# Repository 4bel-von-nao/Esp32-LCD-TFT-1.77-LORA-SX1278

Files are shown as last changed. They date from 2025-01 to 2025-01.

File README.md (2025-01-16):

# Monitor de potencia con Esp32, LoRa y LCD TFT 1.77"
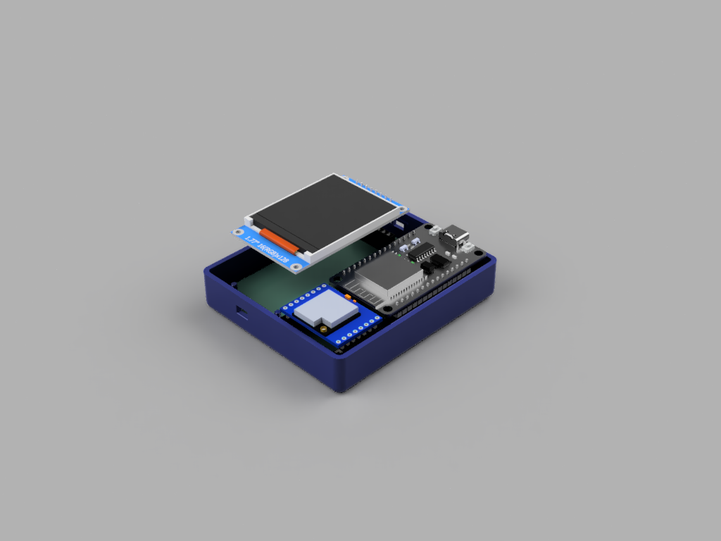
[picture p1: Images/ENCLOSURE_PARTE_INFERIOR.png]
imagen


Este proyecto consiste en un sistema de monitoreo de potencia eléctrica que utiliza un **ESP32** para recepcionar datos de corriente y voltaje
a través de un módulo **LoRa** para luego calcular la potencia consumida.
Se incluyen los diseños del circuito y la PCB realizados en **KiCAD**, y el modelo 3D del dispositivo en **Fusion 360**.

## Componentes principales

- ESP32 (Se usó la versión de 30 pines con conector tipo C).
- LoRa SX1278 RA02.
- LCD TFT 1.77".

## Archivos incluidos

- Codigo: Sketch Arduino
- Diseño PCB: Proyecto KiCad
- Modelos CAD: Archivo Fusion 360

## Problemas y Futuras mejoras

- Debido al intensivo uso del puerto SPI a causa del display LCD, se tuvo que usar puertos diferentes,
el puerto principal para el display y el puerto HSPI para el modulo LoRa, se modificó la libreria
LoRa de sandeepmistry para poder utilizar el puerto HSPI. En el futuro se buscará mejorar esto y poder 
usar un solo puerto para los dos perifericos.

- En el aspecto del diseño mecanico del enclosure, se intentó diseñar los anclajes por medio de tornillos
y roscas M3. Al momento de imprimir no salieron bien tales cuerpos y no pudo cumplir su función. Se replanteará
el diseño para algo más robusto, ya que los anlcajes a presión también son débiles.

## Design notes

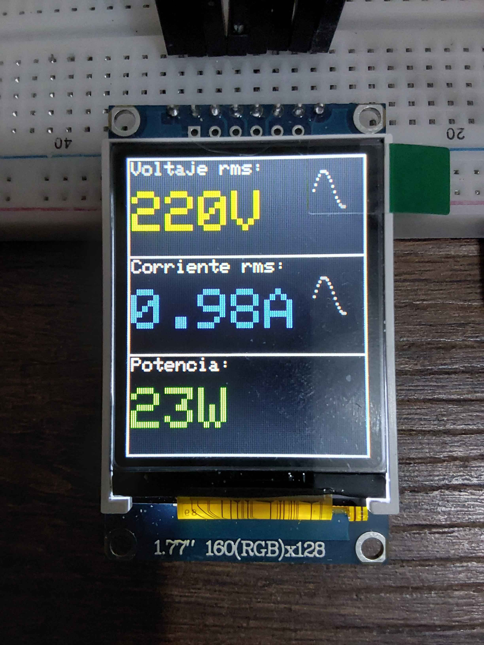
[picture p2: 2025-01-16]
Images/realfoto.jpg

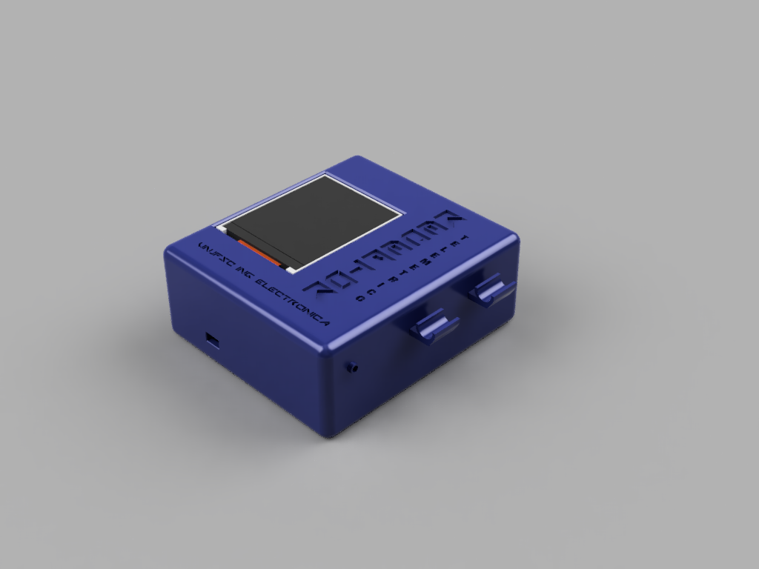
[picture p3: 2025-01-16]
Images/ENCLOSURE.png

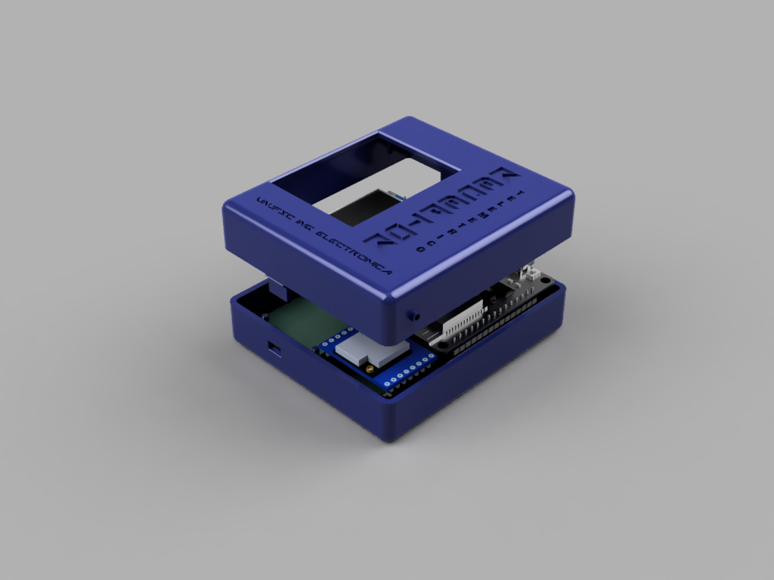
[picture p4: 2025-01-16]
Images/ENCLOSURE1.png

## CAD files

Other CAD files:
CadFiles/ENCLOSURE v9.f3z

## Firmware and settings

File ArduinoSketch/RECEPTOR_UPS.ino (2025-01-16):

#include <Adafruit_GFX.h>   
#include <Adafruit_ST7735.h> 
#include <SPI.h>
#include <LoRaHSPI.h>
//#include "esp_task_wdt.h"

#define TFT_CS 2
#define TFT_RST 21
#define TFT_DC 19
#define TFT_SCLK 18   
#define TFT_MOSI 23
#define BLANCO ST7735_WHITE
#define NEGRO ST7735_BLACK
#define AMARILLO ST7735_YELLOW
#define AZUL ST7735_BLUE
#define VERDE ST7735_GREEN

#define SS   15    // NSS (CS) conectado a GPIO15
#define RST  27     // RST conectado a GPIO27
#define DIO0 33    // DIO0 conectado a GPIO33

String idReceptor   = "TX1";  
String idTransmisor = "TX2";
String datos = "";
int voltaje;
unsigned long tiempoInicio = 0; 
unsigned long tiempoInicio2 = 0; 
int x = 100; int k = 100;
int i = 0;
float frecuencia = 0.3;
int amplitud = 10;
Adafruit_ST7735 tft = Adafruit_ST7735(TFT_CS, TFT_DC, TFT_MOSI, TFT_SCLK, TFT_RST);

void setup(void) {
  Serial.begin(9600);
  LoRa.setPins(SS, RST, DIO0);
  if (!LoRa.begin(433E6)) {  // Cambia la frecuencia según tu región
    Serial.println("Error al inicializar LoRa");
    while (1);
  }
  LoRa.setSpreadingFactor(7);         // SF igual al transmisor
  LoRa.setSignalBandwidth(250E3);    // Ancho de banda igual
  LoRa.setCodingRate4(5);            // Tasa de codificación igual
  LoRa.setPreambleLength(6);         // Preámbulo igual
  delay(1000);
  Serial.println("LoRa inicializado");
 
  xTaskCreate(Task1, "Tarea 1", 1000, NULL, 1, NULL);

  tft.initR(INITR_BLACKTAB);  
  tft.fillScreen(ST7735_BLACK);   
  tft.setTextColor(ST7735_WHITE);
  tft.setTextSize(0);
  tft.setCursor(30,80);
  tft.println("Hello World!");  
  delay(1000);
  tft.fillScreen(ST7735_BLACK); 
  tft.drawRect(0, 0, 128, 160, BLANCO);
  tft.drawLine(0, 53, 128, 53, BLANCO);
  tft.drawLine(0, 106, 128, 106, BLANCO);
}

void loop() { 
  if(millis()-tiempoInicio >= 100){
    rayo();
    seno1();
    seno2();
    tiempoInicio = millis();
  }
  if(millis()-tiempoInicio2 >= 1000){
    Voltaje();
    corriente(datos);
    potencia(datos,voltaje);
    tiempoInicio2 = millis();
  }
}

void Task1(void *pvParameters) {
  while(1) {
    vTaskDelay(10);                        // DELAY DE 10 TICS... O DESACTIVO EL PERRO O LE PONGO EL DELAY
     // Verificar si hay paquetes disponibles
    int packetSize = LoRa.parsePacket();
    if (packetSize) {
      String recibido = "";
      while (LoRa.available()) {
        recibido += (char)LoRa.read();
      }

      // Verificar si el mensaje tiene el identificador correcto
      if (recibido.startsWith(idTransmisor + ":")) {
        datos = recibido.substring(idTransmisor.length() + 1); // Extraer datos después de ":"
        Serial.println(datos);
        int pos1 = datos.indexOf(',');
        int pos2 = datos.indexOf(',');
        datos = datos.substring(0,pos1);
      } else {
        Serial.println("Paquete ignorado: " + recibido);
      }
    }
  }
}

void Voltaje(){
  tft.fillRect(2,16,87,25,NEGRO);
  voltaje = 220;
  voltaje = voltaje + random(-1,1);
  String voltaje2 = String(voltaje);
  tft.setTextColor(BLANCO);
  tft.setTextSize(1);
  tft.setCursor(2,2);
  tft.print("Voltaje rms:");
  tft.setTextColor(AMARILLO);
  tft.setCursor(2,18);
  tft.setTextSize(3);
  tft.print("220"); tft.print("V");
}

void corriente(String datos){
  tft.fillRect(2,71,87,21,NEGRO);
  tft.setTextColor(BLANCO);
  tft.setTextSize(1);
  tft.setCursor(2,55);
  tft.print("Corriente rms:");
  tft.setTextColor(AZUL);
  tft.setCursor(2,71);
  tft.setTextSize(3);
  tft.print(datos); tft.print("A"); 
}

void potencia(String datos, int voltaje){
  tft.fillRect(2,124,87,21,NEGRO);
  float potencia;
  float corriente = datos.toFloat();
  potencia = corriente * voltaje;
  tft.setTextColor(BLANCO);
  tft.setTextSize(1);
  tft.setCursor(2,108);
  tft.print("Potencia:");
  tft.setTextColor(VERDE);
  tft.setCursor(2,124);
  tft.setTextSize(3);
  tft.print(potencia); tft.print("W");
}

void seno1(){
    float seno = amplitud*sin(frecuencia*(x-100));
    int y = 18 - seno;
    tft.drawPixel(x, y, BLANCO);
    x++;

    if (x >= 122) {
      x = 100;  
      //tft.fillScreen(ST77XX_BLACK);  
      tft.fillRect(100,8,22,20,NEGRO);
    }
}

void seno2(){
    float seno = amplitud*sin(frecuencia*(k-100));
    int y = 75 - seno;
    tft.drawPixel(k, y, BLANCO);
    k++;
    if (k >= 122) {
      k = 100;  
      //tft.fillScreen(ST77XX_BLACK);  
      tft.fillRect(100,65,22,20,NEGRO);
    }
}

void rayo(){

  if( i == 0){tft.drawLine(100, 120, 120, 120, BLANCO);}
  if( i == 1){tft.drawLine(99, 121, 119, 121, BLANCO);}
  if( i == 2){tft.drawLine(98, 122, 118, 122, BLANCO);}
  if( i == 3){tft.drawLine(97, 123, 117, 123, BLANCO);}
  if( i == 4){tft.drawLine(96, 124, 116, 124, BLANCO);}
  if( i == 5){tft.drawLine(95, 125, 115, 125, BLANCO);}
  if( i == 6){tft.drawLine(94, 126, 114, 126, BLANCO);}
  if( i == 7){tft.drawLine(93, 127, 113, 127, BLANCO);}
  if( i == 8){tft.drawLine(92, 128, 112, 128, BLANCO);}
  if( i == 9){tft.drawLine(91, 129, 111, 129, BLANCO);}
  if( i == 10){tft.drawLine(90, 130, 110, 130, BLANCO);}
  if( i == 11){tft.drawLine(89, 131, 109, 131, BLANCO);}

  if( i == 12){tft.drawLine(96, 132, 114, 132, BLANCO);}
  if( i == 13){tft.drawLine(96, 133, 113, 133, BLANCO);}
  if( i == 14){tft.drawLine(95, 134, 111, 134, BLANCO);}
  if( i == 15){tft.drawLine(95, 135, 110, 135, BLANCO);}
  if( i == 16){tft.drawLine(94, 136, 108, 136, BLANCO);}
  if( i == 17){tft.drawLine(94, 137, 107, 137, BLANCO);}
  if( i == 18){tft.drawLine(93, 138, 105, 138, BLANCO);}
  if( i == 19){tft.drawLine(93, 139, 104, 139, BLANCO);}
  if( i == 20){tft.drawLine(92, 140, 102, 140, BLANCO);}
  if( i == 21){tft.drawLine(92, 141, 101, 141, BLANCO);}
  if( i == 22){tft.drawLine(91, 142, 99, 142, BLANCO);}
  if( i == 23){tft.drawLine(91, 143, 98, 143, BLANCO);}
  if( i == 24){tft.drawLine(90, 144, 96, 144, BLANCO);}
  if( i == 25){tft.drawLine(90, 145, 95, 145, BLANCO);}
  if( i == 26){tft.drawLine(89, 146, 93, 146, BLANCO);}
  if( i == 27){tft.drawLine(89, 147, 92, 147, BLANCO);}
  if( i == 28){tft.drawLine(88, 148, 90, 148, BLANCO);}
  if( i == 29){tft.drawLine(88, 149, 89, 149, BLANCO);}
  if( i == 30){tft.drawLine(87, 150, 88, 150, BLANCO);}
  if( i == 31){tft.drawLine(87, 151, 87, 151, BLANCO);}
  if( i == 32){tft.drawLine(86, 152, 86, 152, BLANCO);}  
  i++;
  if(i>=31){
    tft.fillRect(86,120,34,32,NEGRO);
    i=0;
  }
}

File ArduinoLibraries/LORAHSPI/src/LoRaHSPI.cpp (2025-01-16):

// Copyright (c) Sandeep Mistry. All rights reserved.
// Licensed under the MIT license. See LICENSE file in the project root for full license information.

#include <LoRaHSPI.h>

// registers
#define REG_FIFO                 0x00
#define REG_OP_MODE              0x01
#define REG_FRF_MSB              0x06
#define REG_FRF_MID              0x07
#define REG_FRF_LSB              0x08
#define REG_PA_CONFIG            0x09
#define REG_OCP                  0x0b
#define REG_LNA                  0x0c
#define REG_FIFO_ADDR_PTR        0x0d
#define REG_FIFO_TX_BASE_ADDR    0x0e
#define REG_FIFO_RX_BASE_ADDR    0x0f
#define REG_FIFO_RX_CURRENT_ADDR 0x10
#define REG_IRQ_FLAGS            0x12
#define REG_RX_NB_BYTES          0x13
#define REG_PKT_SNR_VALUE        0x19
#define REG_PKT_RSSI_VALUE       0x1a
#define REG_RSSI_VALUE           0x1b
#define REG_MODEM_CONFIG_1       0x1d
#define REG_MODEM_CONFIG_2       0x1e
#define REG_PREAMBLE_MSB         0x20
#define REG_PREAMBLE_LSB         0x21
#define REG_PAYLOAD_LENGTH       0x22
#define REG_MODEM_CONFIG_3       0x26
#define REG_FREQ_ERROR_MSB       0x28
#define REG_FREQ_ERROR_MID       0x29
#define REG_FREQ_ERROR_LSB       0x2a
#define REG_RSSI_WIDEBAND        0x2c
#define REG_DETECTION_OPTIMIZE   0x31
#define REG_INVERTIQ             0x33
#define REG_DETECTION_THRESHOLD  0x37
#define REG_SYNC_WORD            0x39
#define REG_INVERTIQ2            0x3b
#define REG_DIO_MAPPING_1        0x40
#define REG_VERSION              0x42
#define REG_PA_DAC               0x4d

// modes
#define MODE_LONG_RANGE_MODE     0x80
#define MODE_SLEEP               0x00
#define MODE_STDBY               0x01
#define MODE_TX                  0x03
#define MODE_RX_CONTINUOUS       0x05
#define MODE_RX_SINGLE           0x06
#define MODE_CAD                 0x07

// PA config
#define PA_BOOST                 0x80

// IRQ masks
#define IRQ_TX_DONE_MASK           0x08
#define IRQ_PAYLOAD_CRC_ERROR_MASK 0x20
#define IRQ_RX_DONE_MASK           0x40
#define IRQ_CAD_DONE_MASK          0x04
#define IRQ_CAD_DETECTED_MASK      0x01

#define RF_MID_BAND_THRESHOLD    525E6
#define RSSI_OFFSET_HF_PORT      157
#define RSSI_OFFSET_LF_PORT      164

#define MAX_PKT_LENGTH           255

#if (ESP8266 || ESP32)
    #define ISR_PREFIX ICACHE_RAM_ATTR
#else
    #define ISR_PREFIX
#endif
SPIClass hspi(HSPI);

LoRaClass::LoRaClass() :
  _spiSettings(LORA_DEFAULT_SPI_FREQUENCY, MSBFIRST, SPI_MODE0),
  _spi(&hspi),
  _ss(LORA_DEFAULT_SS_PIN), _reset(LORA_DEFAULT_RESET_PIN), _dio0(LORA_DEFAULT_DIO0_PIN),
  _frequency(0),
  _packetIndex(0),
  _implicitHeaderMode(0),
  _onReceive(NULL),
  _onCadDone(NULL),
  _onTxDone(NULL)
{
  // overide Stream timeout value
  setTimeout(0);
}

int LoRaClass::begin(long frequency)
{
#if defined(ARDUINO_SAMD_MKRWAN1300) || defined(ARDUINO_SAMD_MKRWAN1310)
  pinMode(LORA_IRQ_DUMB, OUTPUT);
  digitalWrite(LORA_IRQ_DUMB, LOW);

  // Hardware reset
  pinMode(LORA_BOOT0, OUTPUT);
  digitalWrite(LORA_BOOT0, LOW);

  pinMode(LORA_RESET, OUTPUT);
  digitalWrite(LORA_RESET, HIGH);
  delay(200);
  digitalWrite(LORA_RESET, LOW);
  delay(200);
  digitalWrite(LORA_RESET, HIGH);
  delay(50);
#endif

  // setup pins
  pinMode(_ss, OUTPUT);
  // set SS high
  digitalWrite(_ss, HIGH);

  if (_reset != -1) {
    pinMode(_reset, OUTPUT);

    // perform reset
    digitalWrite(_reset, LOW);
    delay(10);
    digitalWrite(_reset, HIGH);
    delay(10);
  }

  // start SPI
  _spi->begin();

  // check version
  uint8_t version = readRegister(REG_VERSION);
  if (version != 0x12) {
    return 0;
  }

  // put in sleep mode
  sleep();

  // set frequency
  setFrequency(frequency);

  // set base addresses
  writeRegister(REG_FIFO_TX_BASE_ADDR, 0);
  writeRegister(REG_FIFO_RX_BASE_ADDR, 0);

  // set LNA boost
  writeRegister(REG_LNA, readRegister(REG_LNA) | 0x03);

  // set auto AGC
  writeRegister(REG_MODEM_CONFIG_3, 0x04);

  // set output power to 17 dBm
  setTxPower(17);

  // put in standby mode
  idle();

  return 1;
}

void LoRaClass::end()
{
  // put in sleep mode
  sleep();

  // stop SPI
  _spi->end();
}

int LoRaClass::beginPacket(int implicitHeader)
{
  if (isTransmitting()) {
    return 0;
  }

  // put in standby mode
  idle();

  if (implicitHeader) {
    implicitHeaderMode();
  } else {
    explicitHeaderMode();
  }

  // reset FIFO address and paload length
  writeRegister(REG_FIFO_ADDR_PTR, 0);
  writeRegister(REG_PAYLOAD_LENGTH, 0);

  return 1;
}

int LoRaClass::endPacket(bool async)
{
  
  if ((async) && (_onTxDone))
      writeRegister(REG_DIO_MAPPING_1, 0x40); // DIO0 => TXDONE

  // put in TX mode
  writeRegister(REG_OP_MODE, MODE_LONG_RANGE_MODE | MODE_TX);

  if (!async) {
    // wait for TX done
    while ((readRegister(REG_IRQ_FLAGS) & IRQ_TX_DONE_MASK) == 0) {
      yield();
    }
    // clear IRQ's
    writeRegister(REG_IRQ_FLAGS, IRQ_TX_DONE_MASK);
  }

  return 1;
}

bool LoRaClass::isTransmitting()
{
  if ((readRegister(REG_OP_MODE) & MODE_TX) == MODE_TX) {
    return true;
  }

  if (readRegister(REG_IRQ_FLAGS) & IRQ_TX_DONE_MASK) {
    // clear IRQ's
    writeRegister(REG_IRQ_FLAGS, IRQ_TX_DONE_MASK);
  }

  return false;
}

int LoRaClass::parsePacket(int size)
{
  int packetLength = 0;
  int irqFlags = readRegister(REG_IRQ_FLAGS);

  if (size > 0) {
    implicitHeaderMode();

    writeRegister(REG_PAYLOAD_LENGTH, size & 0xff);
  } else {
    explicitHeaderMode();
  }

  // clear IRQ's
  writeRegister(REG_IRQ_FLAGS, irqFlags);

  if ((irqFlags & IRQ_RX_DONE_MASK) && (irqFlags & IRQ_PAYLOAD_CRC_ERROR_MASK) == 0) {
    // received a packet
    _packetIndex = 0;

    // read packet length
    if (_implicitHeaderMode) {
      packetLength = readRegister(REG_PAYLOAD_LENGTH);
    } else {
      packetLength = readRegister(REG_RX_NB_BYTES);
    }

    // set FIFO address to current RX address
    writeRegister(REG_FIFO_ADDR_PTR, readRegister(REG_FIFO_RX_CURRENT_ADDR));

    // put in standby mode
    idle();
  } else if (readRegister(REG_OP_MODE) != (MODE_LONG_RANGE_MODE | MODE_RX_SINGLE)) {
    // not currently in RX mode

    // reset FIFO address
    writeRegister(REG_FIFO_ADDR_PTR, 0);

    // put in single RX mode
    writeRegister(REG_OP_MODE, MODE_LONG_RANGE_MODE | MODE_RX_SINGLE);
  }

  return packetLength;
}

int LoRaClass::packetRssi()
{
  return (readRegister(REG_PKT_RSSI_VALUE) - (_frequency < RF_MID_BAND_THRESHOLD ? RSSI_OFFSET_LF_PORT : RSSI_OFFSET_HF_PORT));
}

float LoRaClass::packetSnr()
{
  return ((int8_t)readRegister(REG_PKT_SNR_VALUE)) * 0.25;
}
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
